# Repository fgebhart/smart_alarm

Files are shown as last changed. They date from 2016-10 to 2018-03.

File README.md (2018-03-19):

# Welcome to "_Smala_" - the IoT Smart Alarm Clock



This smart_alarm project provides an easy to build and program Internet of Things alarm clock. We would love to see you build your own version of it. It is designed, such that you can adapt your needs and improve it easily. Let us know if you want to contribute to this repository or simply want to share your ideas. All kinds of support is appreciated. 

# Instructions - Wiki

 :warning: :warning: **THIS PROJECT IS STILL IN DEVELOPMENT AND MIGHT NOT RUN AS EXPECTED**  :warning: :warning:

If you want to build and code your own _smart_alarm_ please visit the **[Smala Wiki](https://github.com/fgebhart/smart_alarm/wiki)**

Or if you just want to dive into the code, simply clone this repository to your computer / Raspberry Pi Zero:

```
cd
git clone https://github.com/fgebhart/smart_alarm.git
```

Also check out our Video on Youtube:

<a href="https://www.youtube.com/watch?v=BQ0yeRbUKlk" target="_blank">IMAGE ALT TEXT HERE</a>

If you want to 3D-print your case, please follow **[this link to thingiverse](http://www.thingiverse.com/thing:2009740)**. Note the [project page on hackaday](https://hackaday.io/project/19230-iot-smart-alarm-clock).

# Smala_v2 Release

We recently released the **v2 version** which includes several new features:

* manage your local mp3 files via the inbuild webinterface
* imrproved 3d printable case
* bugfixes and code improvements
    ... and for sure we proudly present:
* flashy RGB LEDs - for a smoother wakeup



The ***v1 version*** was already born with the following features:

* text to speech synthesizer
* three ways of wake-up sound:
    - play local mp3 files
    - play internet radio station and
    - play latest news as podcast (independent to the alarm time)
* set alarm via smartphone or any other computer
* running apache2 server
* automatic display brightness adjustment due to inbuilt photocell
* audio amplifier volume control
* 3D-printalbe case
* case built-in tactile switch
* alphanumeric display shows text
* 3W speaker definitely wakes you up

### Thanks 

We also would like to say thanks to <a href="https://github.com/aterrien">Anthony Terrien</a> for the <a href="https://github.com/aterrien/jQuery-Knob">jQuery Knob Controls</a>! <a href="https://github.com/ikalnytskyi">Ihor Kalnytskyi</a> for the <a href="https://github.com/ikalnytskyi/listbox.js">jQuery List Box</a>! And also to <a href="http://touchpunch.furf.com/">jQuery UI Touch Punch</a> and <a href="https://jqueryui.com/">jQeury UI</a>.

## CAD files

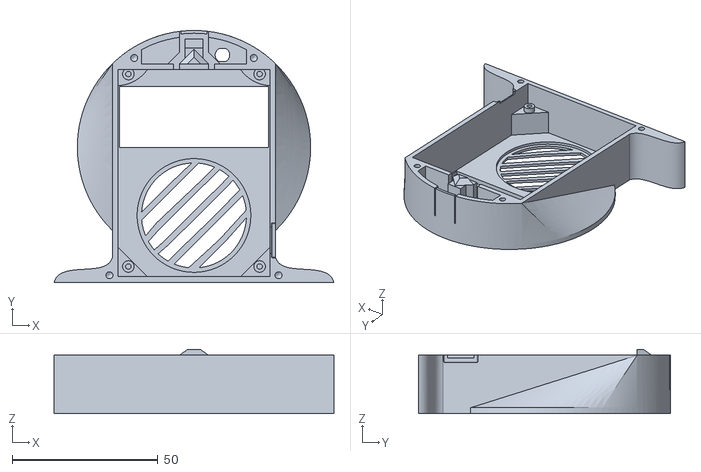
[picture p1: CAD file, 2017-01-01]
3d-print/smart_alarm_FRONT.stl
96.0 x 86.4 x 22.0

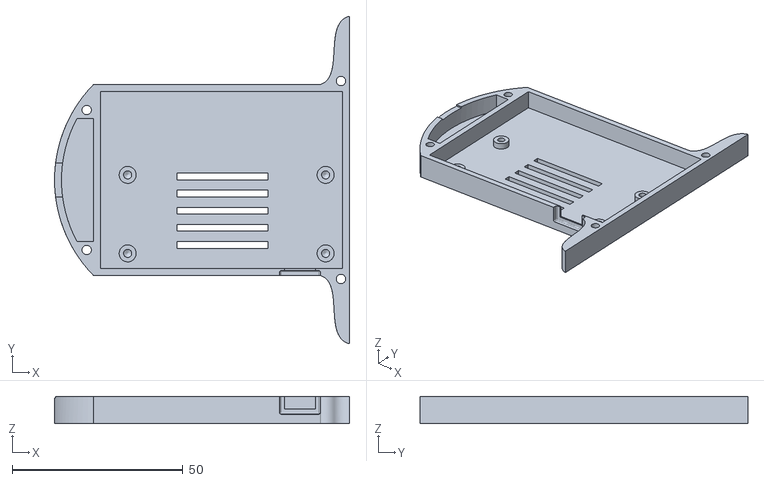
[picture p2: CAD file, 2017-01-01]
3d-print/smart_alarm_BACK.stl
86.4 x 96.0 x 8.00

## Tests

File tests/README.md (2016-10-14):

# smart alarm
open source alarm clock

### Features:

* set alarm using your smart phone via local host server
* play music of choice
* wake up with the latest news no matter what time it is
* speaks with you
* displays text on the 14-segment display
* 3d-printed case

### Picture of the current vesion:

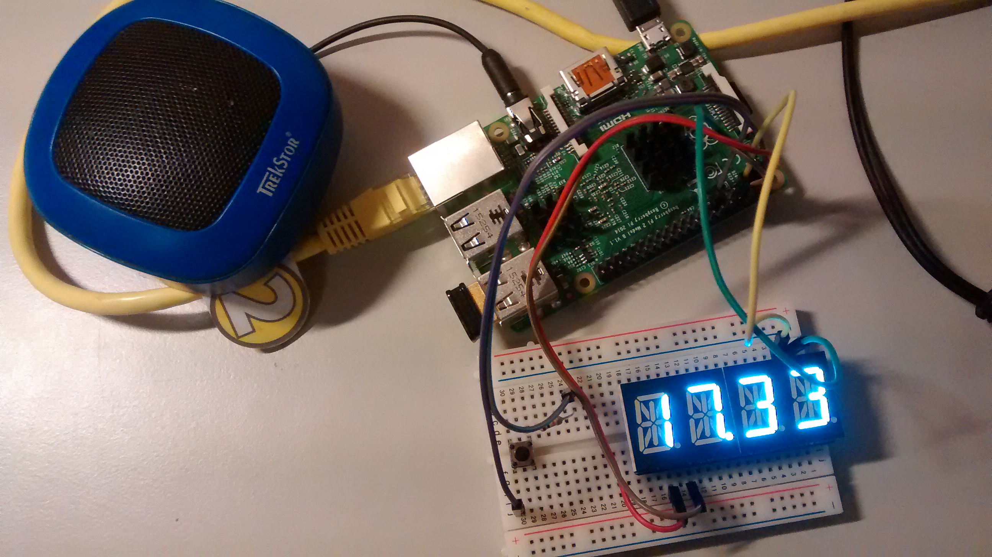
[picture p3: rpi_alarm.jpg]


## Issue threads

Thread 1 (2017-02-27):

smart_alarm display errors

mjf2708, 2017-02-27:
I'm continually getting errors when I try to run smart_alarm/tests/display_time.py:

pi@raspberrypi:~/smart_alarm/tests $ python display_time.py
Traceback (most recent call last):
  File "display_time.py", line 9, in <module>
    display.begin()
  File "build/bdist.linux-armv6l/egg/Adafruit_LED_Backpack/HT16K33.py", line 53, in begin
  File "build/bdist.linux-armv6l/egg/Adafruit_GPIO/I2C.py", line 127, in writeList
  File "build/bdist.linux-armv6l/egg/Adafruit_PureIO/smbus.py", line 274, in write_i2c_block_data
IOError: [Errno 5] Input/output error

I've followed instructions, installed all packages, and other functions (e.g., sound) work OK.

fgebhart, 2017-02-27:
make sure your i2c is enabled via `sudo raspi-config` -> `interfacing options`.

If this doesn't help, you have to check through your wiring one more time. Seems like it is not connected properly, [like pointed out here](https://github.com/adafruit/Adafruit_Python_CharLCD/issues/19).

Also consider the [adafruit tutorial](https://learn.adafruit.com/14-segment-alpha-numeric-led-featherwing/) for more information about the alphanumeric display.

mjf2708, 2017-02-27:
Thanks - this was a simple wiring problem (was working, one wire became disconnected!)

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

Closed 2017-02-27.

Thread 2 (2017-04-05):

Confusing audio instructions

cmcknight, 2017-04-05:
Hi!

I'm building the project per the instructions on the wiki. In the audio section, you mention that there are two low-band pass filters but that was a left-over from the original design that required two speakers. From that, I'm inferring that Fritzing diagram may not be correct. Is that correct and if so, could you post a correct diagram?

Thanks!

fgebhart, 2017-04-05:
Hey,

if you build the smart alarm like shown in the Fritzing schematic, it will work. This means the Fritzing is correct, even though there is some extra information in it which you could leave out. Meaning the additional low-pass filter you mentioned. Since this project makes use of just one speaker, you also might need to use just one low-pass filter. Just make sure that the pwm audio signal of the Raspberry Pi (e.g. left) is connected to the same channel as the speaker (also left) in the amplifier. Sure thing I'll update the Fritzing to leave out the unneeded low-pass filter... sometime... in the future...

Let me know if there is still something unclear!

fgebhart, 2017-07-15:
Updated Fritzing schematics and parts of the wiki. Now all correct!
check: https://github.com/fgebhart/smart_alarm/wiki#wiring

Closed 2017-07-15.

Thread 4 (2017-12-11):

Importing a file shouldn't change the debuglevel

Spindel, 2017-12-11:
https://github.com/fgebhart/smart_alarm/blob/e90c21b0d0854cf2520a9bb973813bf5cc15ad47/smart_alarm/sounds.py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

writing code like:
import logging
logging.basicConfig()
logging.setLevel(logging.ERROR)
import sounds

will currently change the loglevel(!)   where it shouldn't.

fgebhart, 2018-02-11:
fixed it! The loglevel can be set globally in the `start_smala.py` script.

Closed 2018-02-11.

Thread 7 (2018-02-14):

Amplifier GPIO pin on/off switchin in wrong order

fgebhart, 2018-02-14:
with the current configuration it seems like sometimes the amplifier is switched **on** even though there is no sound to be played. If some sound needs to be played afterwards, the amplifier will be switched **off** and it will not be possible to hear the sound.

https://github.com/fgebhart/smart_alarm/blob/1ad9f7d77b2c258df6527c8002156a7c8d430a51/smart_alarm/modules/sounds.py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

Suggestion: Implement Amplifier GPIO pin switching like a toggle switch. Turns on if off and off if on.

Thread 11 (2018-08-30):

ImportError: No module named coloredlogs

ericmathison007, 2018-08-30:
Bug #1:

	Traceback (most recent call last):
	  File "/home/pi/smart_alarm/smart_alarm/smart_alarm", line 58, in <module>
	    import coloredlogs
	ImportError: No module named coloredlogs

Fix:

	sudo pip install coloredlogs

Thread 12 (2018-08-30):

ImportError: No module named colorschemes

ericmathison007, 2018-08-30:
https://github.com/fgebhart/smart_alarm/blob/44e684cc3541109a76f7a6986a2c6938234dfa3a/smart_alarm/smart_alarm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

**Bug:**

```
Traceback (most recent call last):
  File "/home/pi/smart_alarm/smart_alarm/smart_alarm", line 69, in <module>
    from modules.led import LEDs
  File "/home/pi/smart_alarm/smart_alarm/modules/led.py", line 5, in <module>
    import colorschemes
ImportError: No module named colorschemes
```

**Issue:**

I don't have LEDs installed on my alarm clock. But, your code still tries loading the [LED module](https://github.com/fgebhart/smart_alarm/blob/master/smart_alarm/modules/led.py) anyways:

`from modules.led import LEDs`

The issue is that the LED module then tries loading another module named [colorschemes](https://github.com/tinue/APA102_Pi), which I don't have.

**Fix:**

You should conditionally import the LEDs module with something like:

```
if os.path.isfile('/home/pi/APA102_Pi/colorschemes.py'):
    from modules.led import LEDs
```

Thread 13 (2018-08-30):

LED rainbow loading regardless if running LEDs or not

ericmathison007, 2018-08-30:
https://github.com/fgebhart/smart_alarm/blob/44e684cc3541109a76f7a6986a2c6938234dfa3a/smart_alarm/smart_alarm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

**Bug:**

```
Traceback (most recent call last):
  File "smart_alarm", line 533, in <module>
    v = threading.Thread(target=led.rainbow, args=(10, 1,))
AttributeError: 'NoneType' object has no attribute 'rainbow'
```

**Issue:**

For people like me who aren't running LEDs, your code still attempts to perform an LED rainbow upon loading:

```
# one quick led rainbow
v = threading.Thread(target=led.rainbow, args=(10, 1,))
v.start()
```

**Fix:**

Only run the LED rainbow if the check_if_smartalarm_is_running_leds() function returns true:

```
# one quick led rainbow
if check_if_smartalarm_is_running_leds():
    v = threading.Thread(target=led.rainbow, args=(10, 1,))
    v.start()
```

fgebhart, 2018-09-03:
Hey, thanks a lot for your contribution! I'm happy to see that someone is still interested in what we built. Sadly I did not work on this project for a longer time. If you can submit a pull request, otherwise I'll try to fix the issues as soon as possible.

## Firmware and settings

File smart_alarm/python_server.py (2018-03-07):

import cgi
import sys
import os.path
import logging

import base64   # for decoding mp3 data from web server

# important for apache web server:
project_path = os.environ['smart_alarm_path']
if project_path not in sys.path:
    sys.path.append(project_path)
os.chdir(project_path)

from modules.xml_data import Xml_data


logger = logging.getLogger(__name__)


xml_data = Xml_data(str(project_path) + '/data.xml')

MIME_TABLE = {'.txt': 'text/plain',
              '.html': 'text/html',
              '.css': 'text/css',
              '.xml': 'text/xml',
              '.js': 'application/javascript',
              '.png': 'image/png'}


def application(environ, start_response):
    logger.warning("python_server application started")
    # response for POST
    if environ['REQUEST_METHOD'] == 'POST':
        post = cgi.FieldStorage(
           fp=environ['wsgi.input'],
           environ=environ,
           keep_blank_values=False
        )

        uploaded_mp3_file = {}
        for s in post:
            if 'uploadMp3File' in s:
                fieldName = s[s.find('[')+1:s.find(']')]
                uploaded_mp3_file[fieldName] = post.getvalue(s)
            elif s == 'deleteMp3File':
                os.remove('./music/' + post.getvalue(s))
                xml_data.readFileNamesInMusicDirectory()
            else:
                try:
                    xml_data.changeValue(s, post.getvalue(s))
                    logger.warning("{} changed to {}".format(s, post.getvalue(s)))
                except Exception as e:
                    logger.warning("Error: Couldn't change xml entry {} to {} with error: {}".format(s, post.getvalue(s), e))

        if uploaded_mp3_file:
            mp3_data_base64 = uploaded_mp3_file['fileData'][uploaded_mp3_file['fileData'].find('base64,')+7:]
            # mp3_data = decode_base64(mp3_data_base64)
            f = open('./music/' + uploaded_mp3_file['name'], 'w')
            f.write(base64.b64decode(mp3_data_base64))
            f.close()
            xml_data.readFileNamesInMusicDirectory()

    path = environ['PATH_INFO']
    if path != '/data.xml':
        path = './web' + path
    else:
        path = '.' + path

    if os.path.exists(path):
        if path == './web/':
            path = './web/index.html'
        h = open(path, 'rb')
        content = h.read()
        h.close()

        headers = [('content-type', content_type(path))]
        start_response('200 OK', headers)
        return [content]
    else:
        return show_404_app(environ, start_response, path)


def content_type(path):
    """Return a guess at the mime type for this path
    based on the file extension"""

    name, ext = os.path.splitext(path)

    if ext in MIME_TABLE:
        return MIME_TABLE[ext]
    else:
        return "application/octet-stream"


def show_404_app(environ, start_response, path):
    start_response('404 Not Found', [('content-type','text/html')])
    return ["""<html><h1>""" + path + """ not Found</h1><p>
               That page is unknown. Return to
               the <a href="/">alarm clock</a>.</p>
               </html>""", ]


if __name__ == '__main__':
    from wsgiref.simple_server import make_server
    import webbrowser

    httpd = make_server('', 8090, application)
    logger.debug('Serving on port 8090...')

    url = "http://127.0.0.1:8090"
    webbrowser.open(url)

    try:
        while True:
            logger.debug('Server request.')
            httpd.handle_request()
    except KeyboardInterrupt:  # Strg + C
        httpd.server_close()
        logger.warning('Server Closed.')
    except:
        httpd.server_close()
        logger.error('Error')

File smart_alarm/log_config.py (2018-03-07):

import os

project_path = os.environ['smart_alarm_path']

# logging configuration
log_file = str(project_path) + "/logfiles/smala.log"
logging_level = 'DEBUG'

format_log_file = "%(asctime)s :: %(levelname)s :: " \
                  "%(funcName)s in %(filename)s (l:%(lineno)d) :: %(message)s"
format_console = "%(asctime)s - %(levelname)s - %(filename)s l:%(lineno)d - %(message)s"
logging_dict = {
    'version': 1,
    'disable_existing_loggers': True,   # important to set True to suppress existing loggers from other modules
    'loggers': {
        '': {
            'level': logging_level,
            'handlers': ['console', 'file'],
        },
        #'__main__': {
        #    'level': logging_level,
        #    'handlers': ['console', 'file'],
        #},
        #'modules.sounds': {
        #    'level': logging_level,
        #    'handlers': ['console', 'file'],
        #},
        #'modules.xml_data': {
        #    'level': logging_level,
        #    'handlers': ['console', 'file'],
        #},
        #'modules.led': {
        #    'level': logging_level,
        #    'handlers': ['console', 'file'],
        #},
        #'modules.display_class': {
        #    'level': logging_level,
        #    'handlers': ['console', 'file'],
        #},

    },
    'formatters': {
        'format_for_file': {'format': format_log_file, 'datefmt': '%Y-%m-%d %H:%M:%S'},
        'format_for_console': {'format': format_console, 'datefmt': '%m-%d %H:%M:%S'}
    },
    'handlers': {
        'console': {
            'level': logging_level,
            'class': 'logging.StreamHandler',
            'formatter': 'format_for_console',
            'stream': 'ext://sys.stdout'
        },
        'file': {
            'level': logging_level,
            'class': 'logging.handlers.RotatingFileHandler',
            'formatter': 'format_for_file',
            'filename': log_file,
            'maxBytes': 500000,
            'backupCount': 20
        }
    },
}

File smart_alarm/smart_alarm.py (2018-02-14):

__author__ = 'Fabian Gebhart'


"""
SMART ALARM

Features of this python script so far:
- displaying the actual time on the alphanumeric display
- scrolling text messages through the display
- figuring out the most recent dlf news
- download the news
- play the news
- stop the news play with a tactile button connected to the GPIOs
- talk to you, using text to speech synthesis
- reading the user settings from a xml file (created over html server)
- accept individual wake-up message, if there is none use default
    wake-up message
- delete the unneeded old news file
- display if alarm is activated by turning last decimal point on
- using multithreading in order to:
    * enable decimal point blinking while news are played
    * download news file while saying individual wake-up message
- choose between "news" and "music"
- offline mp3 wake-up music enabled
- dim display brightness, since default value is too damn bright for sleeping
- enabled volume adjustment
- enabled internet radio / music streaming as possible wake-up sound
- button interrupt instead of waiting
- turn off and on amplifier in order to suppress background noise
- checks provided podcast + stream url if they are ok, if not play default url
- possibility to press button without any alarm going: informs you about the next alarm
- writing error log to 'error.log' file
- checks for internet connection 2mins before alarm, since the connection sometimes
    get lost during the night
- flashy RBG LEDs
- enable uploading and organizing mp3 files via webinterface
- enable Spotify interface using mopidy

mpc stations:
OrangeFM                http://orange-01.live.sil.at:8000
SmoothLounge with Ads:  http://streaming.radionomy.com/The-Smooth-Lounge?lang=en-US%2cen%3bq%3d0.8%2cde%3bq%3d0.6

potential podcast stations:
BBC News: http://www.bbc.co.uk/programmes/p02nq0gn/episodes/downloads.rss
DLF News: http://www.deutschlandfunk.de/podcast-nachrichten.1257.de.podcast.xml

"""

import urllib2
import RPi.GPIO as GPIO
import threading
from modules.display_class import Display
from modules.sounds import Sound
import time
import os
from modules.xml_data import Xml_data
from modules.led import LEDs
from xml.dom import minidom
import logging


def button_callback(channel):
    """define a threaded callback function to run when events are detected"""
    start_timer = time.time()
    timer = 0

    if GPIO.input(button_input_pin) and sound.sound_active is False and led.leds_active is False:  # if port 24 == 1
        while GPIO.input(button_input_pin) and timer < 3:
            loop_timer = time.time()
            timer = loop_timer - start_timer
            time.sleep(0.1)

        if timer < 3:
            logging.info('button pressed for < 3 sec')
            tell_when_button_pressed(xml_data.alarm_active(), xml_data.alarm_days(), xml_data.alarm_time())
        if timer >= 3:
            logging.info('button pressed for > 3 sec')
            shutdown_pi()

    elif GPIO.input(button_input_pin):
        if sound.sound_active is True:
            sound.stopping_sound()
        elif led.leds_active is True:
            led.stopping_leds()


def download_file(link_to_file):
    """function for downloading files"""
    file_name = link_to_file.split('/')[-1]
    u = urllib2.urlopen(link_to_file)
    f = open(file_name, 'wb')
    print "-> downloading: %s" % file_name
    logging.debug("downloading file: %s" % file_name)

    # buffer the file in order to download it
    file_size_dl = 0
    block_sz = 8192
    while True:
        buffer = u.read(block_sz)
        if not buffer:
            break

        file_size_dl += len(buffer)
        f.write(buffer)

    f.close()
    # XML file now is saved (to the same directory like this file)
    print "-> download done"
    logging.debug('download done')
    return file_name


def find_most_recent_news_url_in_xml_file(xml_file):
    """parse the xml file in order to find the url in the first item,
    corresponding to the most_recent_news_url"""
    # run XML parser and create a list with all 'enclosure' item urls
    xmldoc = minidom.parse(xml_file)
    itemlist = xmldoc.getElementsByTagName('enclosure')

    # search for 'url' and take the first list element
    most_recent_news_url = itemlist[0].attributes['url'].value

    return most_recent_news_url


def set_ind_msg(ind_msg_active, ind_msg_text):
    """takes and checks the to two arguments and sets the
    individual message"""
    if ind_msg_active == '0':
        # ind msg is deactivated, therefore create default message
        print '-> individual message deactivated - constructing default message'
        sayable_time = str(time.strftime("%H %M"))
        today = time.strftime('%A')
        standard_message = 'good morning. It is ' + today + '  ' + sayable_time
        individual_message = standard_message
    else:
        individual_message = ind_msg_text

    return individual_message


def delete_old_files(time_to_alarm, alarm_active):
    """checks for old mp3 files and deletes them"""
    # find all mp3 files and append them to a list
    list_of_mp3_files = []
    # check the projects directory
    for file in os.listdir(project_path):
        if file.endswith('.mp3'):
            list_of_mp3_files.append(project_path + '/' + str(file))

    # as well check the home folder
    for file in os.listdir('/home/pi'):
        if file.endswith('.mp3'):
            list_of_mp3_files.append('/home/pi/' + str(file))

    # either if the time_to_alarm is 10 minutes away from going off, or if it is deactivated
    if time_to_alarm < -10 or time_to_alarm > 10 or alarm_active == '0':
        for file in range(len(list_of_mp3_files)):
            logging.debug('deleting old mp3 files now')
            os.remove(list_of_mp3_files[file])
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

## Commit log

2016-10-04 python code to read out button pressed for RPI
2016-10-04 playing news on RPI and stop them with pressing a button
2016-10-11 executing python_server.py creates a web server on port 8090; maybe wsgi python module is necessary. Also images for the first button were added
2016-10-14 picture of the current setup :)
2016-11-18 handling wrong folder problem + adding blop sound for volume adjustment
    [sounds.py]
2016-11-18 trying to get things working... without too much confusion
    [play_sound.py, sounds.py]
2016-11-19 managed to get interrupt button working...almost
2016-11-21 added switch wire and colors
2016-11-30 suppress noise and have a stable version 0.8
    [smart_alarm0.8.py, sounds.py]
2016-12-20 avoid too many brightness changes
    [smart_alarm0.8.py]
2016-12-26 added clock; added button for testing the alarm; added textfields for stream and podcast url; textfield for individual message working now; todo: mp3 selection
2016-12-29 soldering display pics
2016-12-30 welcome msg no thread and correct linking with env var
    [smart_alarm0.8.py]
2016-12-30 fritzing showing amp circuit
2016-12-30 fritzing button debounce picture
2016-12-30 new pictures concerning the button
2016-12-30 update wire colors
2017-01-01 fritzing of complete smartalarm circuit
2017-01-01 fritzing graphics corresponding to the provided graphics from github wiki
    [amp_pwm_audio.fzz, button_debounce_zero.fzz, complete circuit.fzz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]
2017-01-01 3d printing files
    [smart_alarm_BACK.stl, smart_alarm_FRONT.stl]
2017-01-02 3d-model case pics
2017-01-06 enable -tell-time-to-alarm-when-button-pressed and podcast url usage
2017-01-07 added functionality to exec smart_alarm.test_alarm() function. Todo: Find a way that python_server.py can still executed on a non raspberry system
2017-01-24 enable logging to error.log file
    [display_class.py, smart_alarm.py, sounds.py]
2017-01-24 test_alarm button on web surface no changes the value of test_alarm in the xml file to 1
2017-01-24 enable test alarm button
2017-02-01 enable logging and first attempts to get leds running
2017-02-04 run_alarm implemented as one function, error.log is always saved in project folder
    [smart_alarm.py]
2017-02-04 led class planned to controle the leds
2017-02-16 led class now makes use of APA102C LEDs, aka Adafruit_Dotstar
2017-02-16 ready for led implementation, but still runs without any leds connected
2017-02-17 new seperate python for running smartalarm with RGB LEDs
2017-07-15 bugfix: find music directory with env var path
    [xml_data.py]
2017-07-15 no need for seperate smart_alarmLED.py script, main programm now checks if LEDs installed
2017-07-24 disabling error log for wlan connectivity check
    [smart_alarm.py]
2017-07-24 update amp switch pin
2018-02-26 modulo timer for blinking dot, logging with log_config.py
2018-02-28 fix delete_old_files bug - colorize console logging
    [display_class.py, led.py, log_config.py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]
